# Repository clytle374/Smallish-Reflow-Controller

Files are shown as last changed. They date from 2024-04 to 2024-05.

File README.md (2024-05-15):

# Smallish-Reflow-Controller

This code started as Tiny Reflow Controller and adapted and modified https://github.com/rocketscream/TinyReflowController  While some of the original code still exists like much of the display, it was more of a teaching tool for me at this point.

This runs on a ATmega644PA processor on a MightyCore board for development. So the MightyCore board library needs loaded to build with the Arduino IDE. It uses a 128x64 OLED display with the SSD1306 driver and MAX6675 thermocouple chip plus outputs for SSR(I also added a 4N35 opto), servo and buzzer.

Here is the basic setup of the reflow profiles.  There are 2 profiles one for lead and another for lead free, the parameters in this chart have separate entries for each profile.

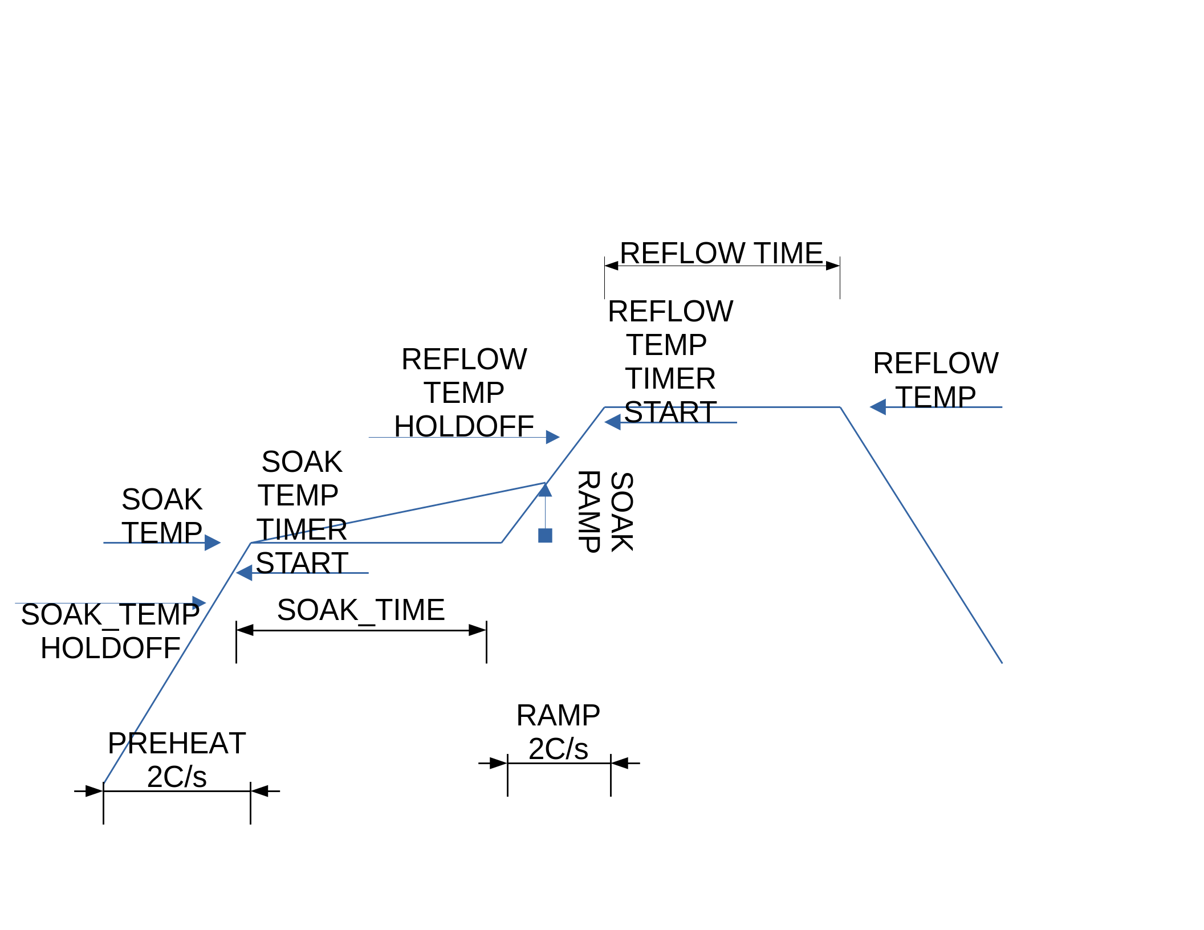
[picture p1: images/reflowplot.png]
Parameters and useage


This is a overview of the settings, more later on the oven and how the code works.  Preheat is set at 2C/s. If your oven cannot hold a 2C/s ramp, I am not sure this code will work out very well on your oven. The ramp will continue until the SOAK_TEMP_HOLDOFF is reached.  Its value is the number of degrees before the SOAK_TEMP. So if SOAK_TEMP is 150C and SOAK_TEMP_HOLDOFF is 25C then the elements will cut out at 125C. Temperature overshoot will come close to reaching the SOAK_TEMP. The SOAK_TIME will start when SOAK_TIMER_TEMP is reached. If the delta temp becomes too low during this the time the program will start adding small pulses of temperature increase, the display will show “RECOVER” at the bottom. There is an option for adding in a SOAK_RAMP to increase the temp linearly over the soak cycle, setting it to 0 disables it.

At the end of the soak cycle a 2C/s ramp is started.  Just like the SOAK_TEMP_HOLDOFF the heaters will cutoff at the value of REFLOW_TEMP_HOLDOFF before REFLOW_TEMP temp is reached. Once REFLOW_TIMER_TEMP is reached the timer will start and hold temperature until the set REFLOW_TIME is reached.

Why use those holdoff values?  I could not tune the PID of the system to not overshoot severely and hold a steady temperature. In researching this issue I found this quote “The unfortunate relationship between servo systems and oscillators is very apparent in thermal control systems.” by  Jim Williams

Results
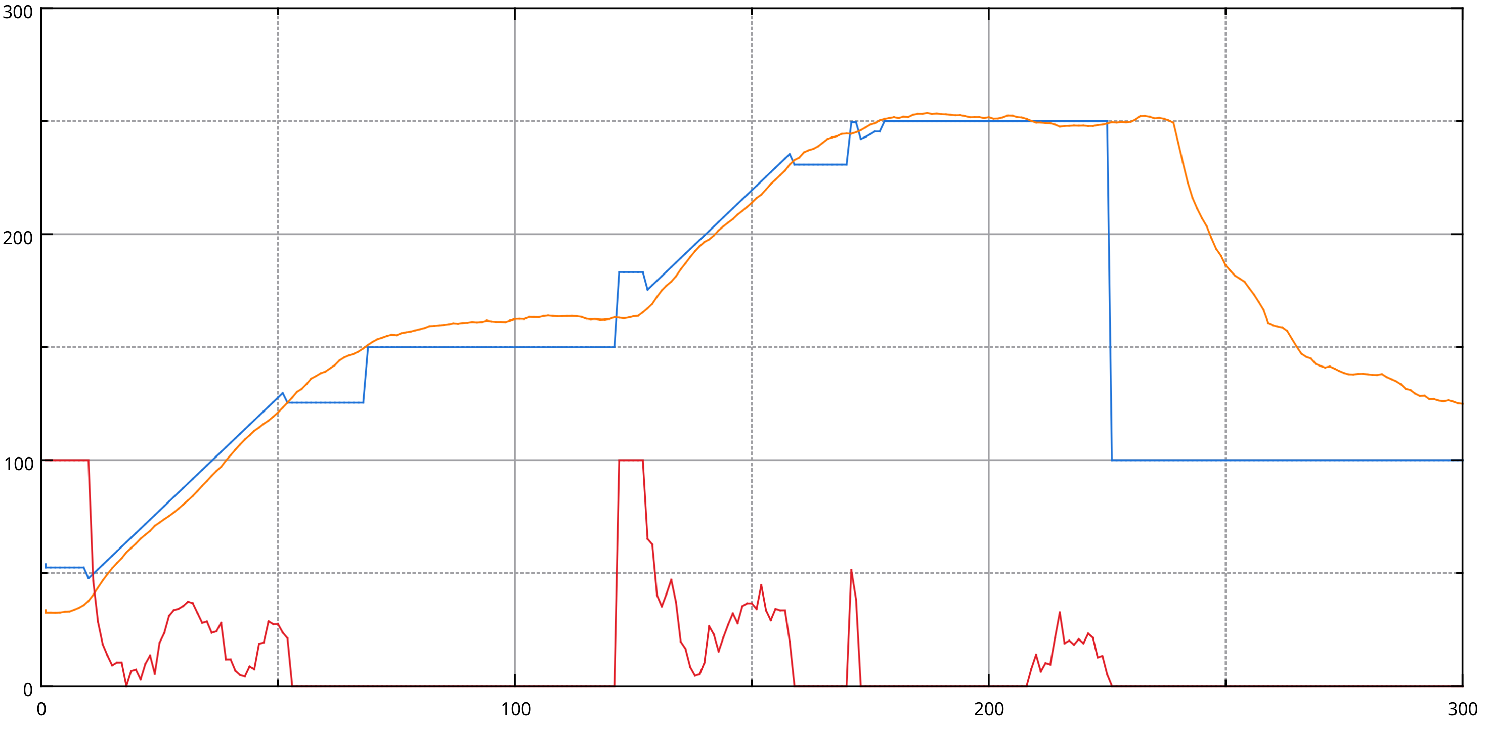
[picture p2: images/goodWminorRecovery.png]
Good Run

Blue= Setpoint       Orange= Temperature        Red= Output %
You can see the recovery right before the oven hits reflow temp. Below is an example of the TEMP_HOLDOFF values being too large making the reflow cycle too long.
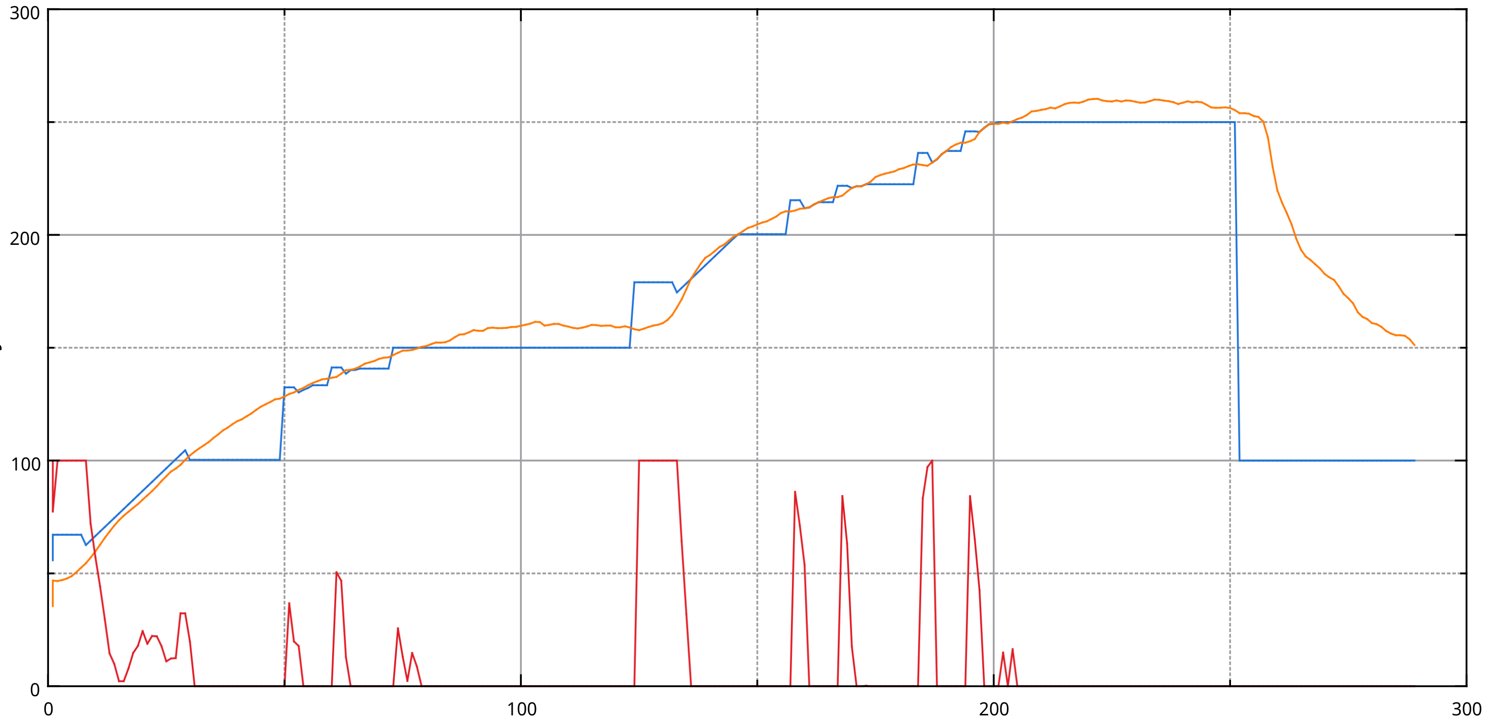
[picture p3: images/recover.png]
Too much Recovery


The oven is based on a $20 toaster oven from Walmart (MS54100112163), 2 of them actually as the whole oven is cheaper than one heating element. Each oven has a 470 watt and 580 watt quartz elements.  The oven was fitted with an insert made from the second oven and aluminum flashing as the top half of the chamber for less heat mass. It was insulated with Kaowool, and cheap aluminum coated fiberglass adhesive on the inside. The quarts tubes were cut shorter with a diamond wheel in a dreamil tool and all 4 were put in the bottom, giving about 2KW.  In hindsight I would have tried using aluminum flashing with koawool across the bottom/back/top before I cut the elements. 4 holes were drilled though the oven sides and into the chamber.  Sheet metal screws were then used as stay bolts to hold it in place.  One of the element shields was used at the bottom front to protect the glass due to their close proximity.  It might not be needed, but it greatly stiffens the chamber.

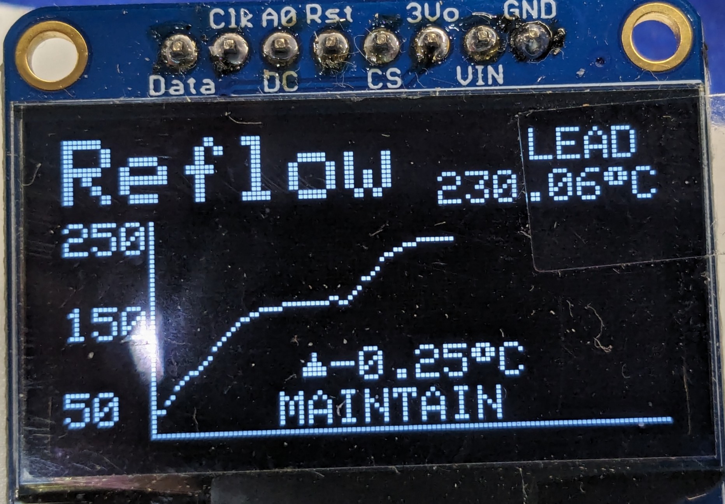
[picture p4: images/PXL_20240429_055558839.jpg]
Display

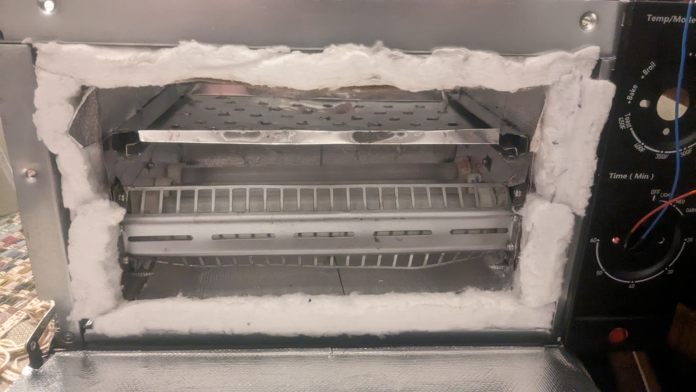
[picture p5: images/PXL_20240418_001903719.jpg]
Chamber Installed

Making the chamber
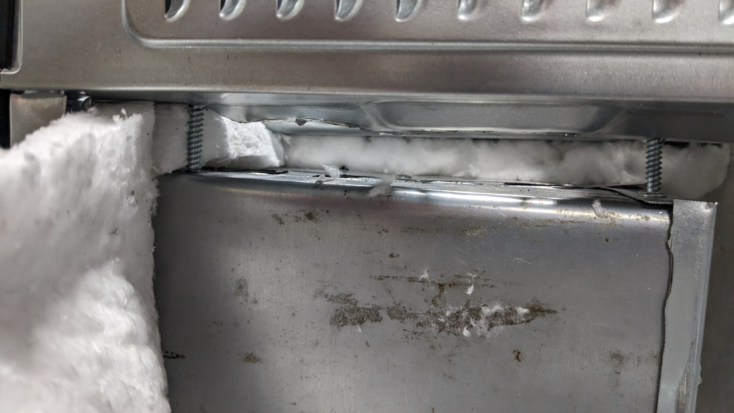
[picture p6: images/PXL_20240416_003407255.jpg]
Staybolts

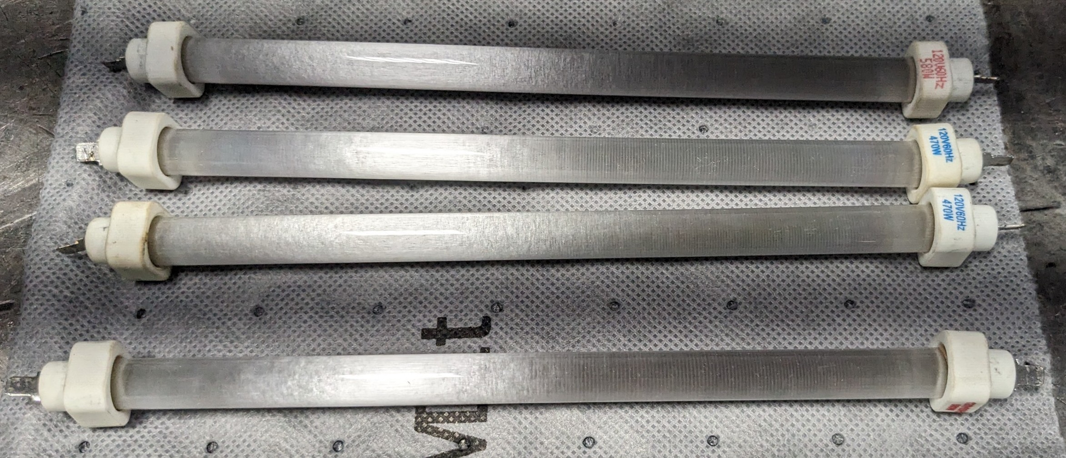
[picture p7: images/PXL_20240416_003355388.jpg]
Cut down elements

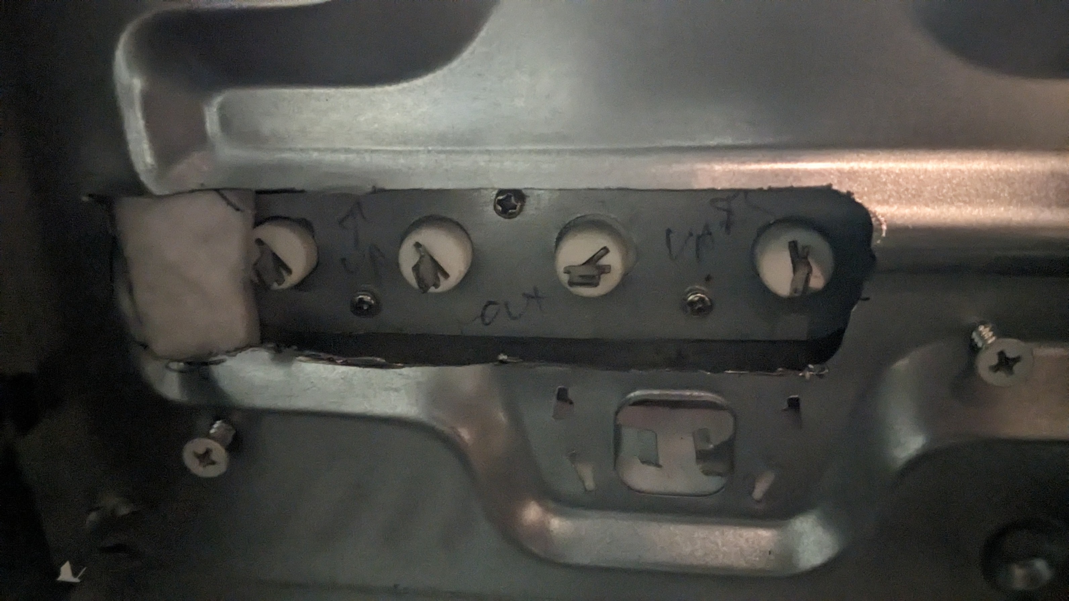
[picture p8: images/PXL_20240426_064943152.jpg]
elements holder


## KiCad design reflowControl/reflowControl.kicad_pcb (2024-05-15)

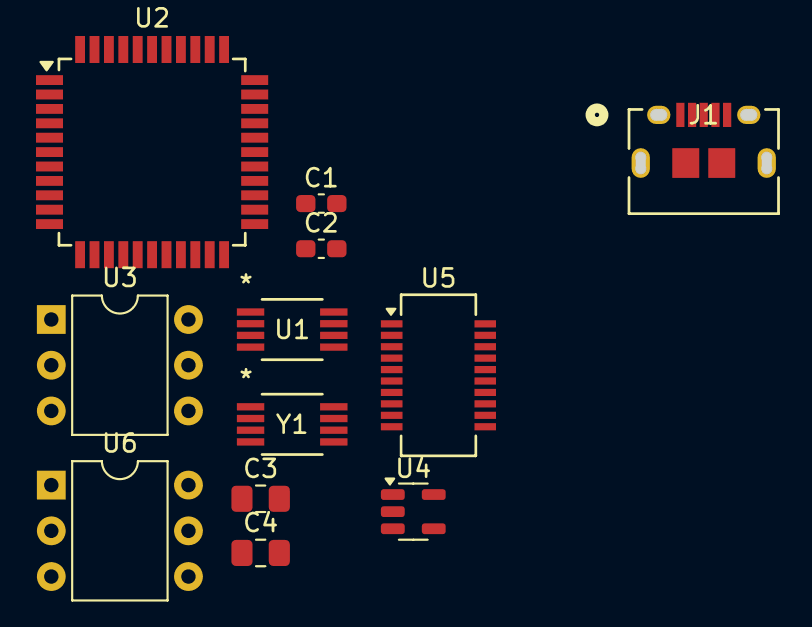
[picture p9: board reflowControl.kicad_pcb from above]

Board: 2 copper layers, 12 parts (0 on the bottom side), 6 nets, no tracks yet.

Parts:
C1, C2: 1u; C_0603_1608Metric_Pad1.08x0.95mm_HandSolder
C3, C4: 22p; C_0805_2012Metric_Pad1.18x1.45mm_HandSolder
J1: 10118194-0001LF; CONN_10118194-0001LF_AMP
U1: MAX6675ISA+; 21-0041B_8_MXM-M
U2: ATmega644PA-A; TQFP-44_10x10mm_P0.8mm
U3, U6: 4N35; DIP-6_W7.62mm
U4: MIC5317-3.3xM5; SOT-23-5
U5: FT231XS; SSOP-20_3.9x8.7mm_P0.635mm
Y1: Crystal; 21-0041B_8_MXM-M

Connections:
GND: C1.2, C2.2, C3.2, C4.2, U2.6 (GND), U2.18 (GND), U2.28 (GND), U2.39 (GND), U3.2, U4.2 (GND)
unnamed: U2.5 (VCC), U2.17 (VCC), U2.38 (VCC)
unnamed: C3.1, U2.8 (XTAL1), Y1.1
unnamed: C4.1, U2.7 (XTAL2), Y1.2
unnamed: C1.1, U4.1 (VIN), U4.3 (EN)
unnamed: C2.1, U4.5 (VOUT)

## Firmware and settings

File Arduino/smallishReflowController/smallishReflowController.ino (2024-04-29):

#define version 38

/*Title: Smallish Reflow Controller
  Date: 04-26-2024
  Author: Cory Lytle  KO4SWI

  This code was taken from Tiny Reflow Controller and adapted and modified, only 
  some parts of the structure remain, and its exellent display code.
  Thermocouple controller was changed to a MAX6657 and buttons were 
  replaced with a encoder button to enable settings configuration at the panel.
  The origonal code wouldn't run from on a 328P due to, I believe, running out of memory.  
  So it was moved to a ATmega644 processor on a MightyCore board for development. 
  So the MightyCore board needs loaded to build with the Arduino IDE.
  A servo to open the door is being added.   
  https://github.com/clytle374/Smallish-Reflow-Controller


  V31 organizing and commenting    
  V32 fixing menus, some bugs(known) remain        
  V33 fixed menus minor tweeks and the modes only moving 1 way with encoder        
  V34 clean, fix menus still, removed dead code,  
  V35 deleting extra junk, a few misc bugs
  V36 more cleanup, removed hardcoded values, work on soak ramp option
  V37 test and fix changes from above.  Need to figure out servo parameters.
  //^^ closed degrees.  Max open degrees. Open for cool ramp for both lead and ROHS?
  V38  found several issues, learned new text strings method that fixed running
  //^^ out of ram and getting trash on the display.  Fixed horriable soak slope issues
  */


//*****************************************************
//********* watchdog is running  *******
//********* charge pump the SSR supply? ***************
//*****************************************************


// ***** INCLUDES *****
#include <SPI.h>   // pulled in by SSD1306?
#include <Wire.h>  // pulled in by SSD1306SOAK_MICRO_PERIOD_PB?
#include <EEPROM.h>
#include <Adafruit_GFX.h>
#include <Adafruit_SSD1306.h>
#include <MAX6675.h>        //https://github.com/RobTillaart/MAX6675
#include <PID_v1.h>         //https://github.com/br3ttb/Arduino-PID-Library
#include <EncoderButton.h>  //https://github.com/Stutchbury/EncoderButton
#include <avr/wdt.h>        // watchdog timer
#include <Servo.h>
//#include <Watchdog.h> //Nadav Matalon   https://github.com/nadavmatalon/WatchDog

#include "smallishReflowController.h"

// ***** TYPE DEFINITIONS *****
typedef enum REFLOW_STATE {  //states for switch statments
  IDLE,
  PREHEAT,
  SOAK,
  REFLOW,
  COOL,
  COMPLETE,
  TOO_HOT,
  ERROR,
  PROGRAM
} reflowState_t;

//states for the reflow modes
typedef enum CURRENT_FUNCTION {  //functions for switch statments
  INTERCEPT,
  RAMP,
  COAST,
  SLOPE,
  MAINTAIN,
  RECOVER,
} currentFunction_t;

typedef enum REFLOW_STATUS {  //reflow yes or no, why not bool?
  OFF,
  ON
} reflowStatus_t;


typedef enum REFLOW_PROFILE {  //switch for ROHS, lead, Program mode
  REFLOW_PROFILE_LEADFREE,
  REFLOW_PROFILE_LEADED,
  PROGRAM_MODE
} reflowProfile_t;


// ***** PID CONTROL VARIABLES *****
double setpoint;    //target temp
double input = 21;  //zero will throw errors before first averaged sample
double outputMain;  //output from PID for main element

//unsorted parameters for whatnots
int windowSize;
unsigned long windowStartTime;
unsigned long nextCheck;    // time keeping variable
unsigned long nextRead;     //next read of thermouple
unsigned long updateLcd;    //display update interval
unsigned long systemTimer;  //timer for running everything in run modes
unsigned long soakTimer;    //timer for soaking
unsigned long reflowTimer;  //timer for relow
unsigned long buzzerPeriod;
unsigned long recoverTimer;
double lastTemp;  //temp last scan

//these are used to pass the diffrent ROHS or lead parameters to the system
unsigned long soakTempHoldoff;  //cut before we get to temp
unsigned long soakTemp;
unsigned long soakStartTemp;
unsigned long soakTempRamp;
unsigned long soakTime;
unsigned long reflowTempHoldoff;
unsigned long reflowTemp;
unsigned long reflowStartTemp;
unsigned long reflowTime;
unsigned long doorOpen;


reflowState_t reflowState;          // Reflow oven controller state machine state variable
reflowStatus_t reflowStatus;        // Reflow oven controller status
reflowProfile_t reflowProfile;      // Reflow profile type
currentFunction_t currentFunction;  //functions inside each state

unsigned int timerSeconds;  // Seconds timer for serial data out, or more?
unsigned int fault;         // Thermocouple fault status variable DOESN'T WORK
unsigned int timerUpdate;
unsigned char temperature[SCREEN_WIDTH - X_AXIS_START];
unsigned char x;
int encoder;                 //stored encoder couunts
bool button = 0;             // is button pressed?
int programPointer = 0;      //what is the current position of the programming menu
int lastPointer;             //save state to catch change
int menuPointer = 10;        // move selector back to parameters
bool edit = 1;               // sw back to edit mode
int menuYes = 0;             // IDK, look into this
int currentBaudPointer = 0;  // pointer for selecting baudrates from list, should be local?
double deltaTemp;
double px[41];  //parameters



// ***** LCD MESSAGES *****
const char* lcdMessagesReflowStatus[] = {  //text for display
  "Ready",
  "Pre",
  "Soak",
  "Reflow",
  "Cool",
  "Done!",
  "Hot!",
  "Error",
  "Prog"
};

// these are the texts for the menu.
const char menuOptions[][4] = { "NO", "YES" };  //display for ON/OFF menu options
const char* parameterNames[] = { "TEMPERATURE_ROOM",
                                 "LF_SOAK_TEMP_HOLDOFF",
                                 "LF_SOAK_TEMP",
                                 "LF_SOAK_TIMER_TEMP",
                                 "LF_SOAK_TIME",
                                 "LF_SOAK_RAMP_TEMP",
                                 "LF_REFLOW_TEMP_HOLFOF",
                                 "LF_REFLOW_TEMP",
                                 "LF_REFLOW_TIMER_TEMP",
                                 "LF_REFLOW TIME",
                                 "LF_DOOR_OPEN_DEG",
                                 "PB_SOAK_TEMP_HOLDOFF",
                                 "PB_SOAK_TEMP",
                                 "PB_SOAK_TIMER_TEMP",
                                 "PB_SOAK_TIME",
                                 "PB_SOAK_RAMP_TEMP",
                                 "PB_REFLOW_TEMP_HOLDOF",
                                 "PB_REFLOW_TEMP",
                                 "PB_REFLOW_TIMER_TEMP",
                                 "PB_REFLOW_TIME",
                                 "PB_DOOR_OPEN_DEG",
                                 "PID_KP_PREHEAT_MAIN ",
                                 "PID_KI_PREHEAT_MAIN",
                                 "PID_KD_PREHEAT_MAIN",
                                 "PID_KP_SOAK_MAIN",
                                 "PID_KI_SOAK_MAIN",
                                 "PID_KD_SOAK_MAIN",
                                 "PID_KP_REFLOW_MAIN",
                                 "PID_KI_REFLOW_MAIN",
                                 "PID_KD_REFLOW_MAIN",
                                 "MAX_ON   1 to 100%",
                                 "TEMPERATURE_COOL_MIN",
                                 "DOOR_CLOSED_DEG",
                                 "DOOR_FULL_OPEN_DEG",
                                 "SERIAL_SPEED",
                                 "EXIT",
                                 "DUMP_TO_SERIAL",
                                 "LOAD_DEFAULT_SETTINGS",
                                 "SAVE_TO_EEPROM" };



const char* currentFunctionText[] = {  //names for Functions
  "INTERCEPT",
  "RAMP",
  "COAST",
  "SLOPE",
  "MAINTAIN",
  "RECOVER"
};
//this will load the defaults parameters.. menu will use to load to defaults
const double defaultpx[41] = { TEMPERATURE_ROOM,
                               LF_SOAK_TEMP_HOLDOFF,
                               LF_SOAK_TEMP,
                               LF_SOAK_TIMER_TEMP,
                               LF_SOAK_TIME,
                               LF_SOAK_RAMP_TEMP,
                               LF_REFLOW_TEMP_HOLFOFF,
                               LF__REFLOW_TEMP,
                               LF_REFLOW_TIMER_TEMP,
                               LF_REFLOW_TIME,
                               LF_DOOR_OPEN_DEG,
                               PB_SOAK_TEMP_HOLDOFF,
                               PB_SOAK_TEMP,
                               PB_SOAK_TIMER_TEMP,
                               PB_SOAK_TIME,
                               PB_SOAK_RAMP_TEMP,
                               PB_REFLOW_TEMO_HOLDOFF,
                               PB_REFLOW_TEMP,
                               PB_REFLOW_TIMER_TEMP,
                               PB_REFLOW_TIME,
                               PB_DOOR_OPEN_DEG,
                               PID_KP_PREHEAT_MAIN,
                               PID_KI_PREHEAT_MAIN,
                               PID_KD_PREHEAT_MAIN,
                               PID_KP_SOAK_MAIN,
                               PID_KI_SOAK_MAIN,
                               PID_KD_SOAK_MAIN,
                               PID_KP_REFLOW_MAIN,
                               PID_KI_REFLOW_MAIN,
                               PID_KD_REFLOW_MAIN,
                               MAX_ON_MAIN,
                               TEMPERATURE_COOL_MIN,
                               DOOR_CLOSED_DEG,
                               DOOR_FULL_OPEN_DEG,
                               SERIAL_SPEED,
                               0,
                               0,
                               0,
                               0 };



//uncomment this when skipping loading the eeprom
// *******************   BROKEN    ****************
/*double px[31] = { TEMPERATURE_ROOM, LF_SOAK_TEMP_HOLDOFF, LF_SOAK_TEMP,
                  LF_SOAK_TIME, LF_SOAK_RAMP_TEMP, LF_REFLOW_TEMP_HOLFOFF, LF__REFLOW_TEMP,
                  LF_REFLOW_TIME, PB_SOAK_TEMP_HOLDOFF, PB_SOAK_TEMP, PB_SOAK_TIME,
                  PB_SOAK_RAMP_TEMP, PB_REFLOW_TEMO_HOLDOFF, PB_REFLOW_TEMP, PB_REFLOW_TIME,
                  PID_KP_PREHEAT_MAIN, PID_KI_PREHEAT_MAIN, PID_KD_PREHEAT_MAIN, PID_KP_SOAK_MAIN,
                  PID_KI_SOAK_MAIN, PID_KD_SOAK_MAIN, PID_KP_REFLOW_MAIN, PID_KI_REFLOW_MAIN,
                  PID_KD_REFLOW_MAIN, MAX_ON_MAIN, TEMPERATURE_COOL_MIN, SERIAL_SPEED };


*/

//availble baud rates, did I miss anything important?
const double baudRates[14] = { 2400, 4800, 9600, 14400, 19200, 28800, 38400, 57600,
                               74800, 115200, 230400, 250000, 500000, 1000000 };


// PID control initalize // PID values are garbage now since I can not load eeprom yet
PID reflowOvenPIDmain(&input, &outputMain, &setpoint, 100, .025, 20, DIRECT);

//initalize oled display
Adafruit_SSD1306 oled(SCREEN_WIDTH, SCREEN_HEIGHT, &Wire, -1);

// MAX6675 thermocouple interface
MAX6675 thermoCouple(MAX6675_CS_PIN, &SPI);  //sets up the thermocouple chip

EncoderButton eb1(ROTARY_PIN1, ROTARY_PIN2, BUTTON_PIN);  //sets up the encoder buton

Servo doorServo;  // create servo object to control a servo

void setup() {
  for (int i = 0; i < EXIT; i++) {  //this loop loads eeprom into parameters

    //EEPROM.put(EEPROM_STORAGE_ADDRESS + (i*4) , px[i]);   //this loads eeprom from parameters
    EEPROM.get(EEPROM_STORAGE_ADDRESS + (i * 4), px[i]);  //this loads parameters from eeprom
  }
  for (int i = EXIT; i < SAVE_TO_EEPROM; i++) {  //clear the commands parameters
    px[i] = 0;
  }


  //Serial.begin(SERIAL_SPEED); //trash
  Serial.begin(px[SERIAL_BAUD]);  //set serial speed
  // Check current selected reflow profile
  unsigned char value;  // = EEPROM.read(PROFILE_TYPE_ADDRESS);
  EEPROM.get(PROFILE_TYPE_ADDRESS, value);
  if ((value == 0) || (value == 1)) {
    // Valid reflow profile value
    reflowProfile = value;
  } else {
    // Default to lead-free profile
    EEPROM.put(PROFILE_TYPE_ADDRESS, 0);
    reflowProfile = REFLOW_PROFILE_LEADFREE;
  }

  // SSR pin initialization to ensure reflow oven is off
  digitalWrite(SSR_MAIN, LOW);
  pinMode(SSR_MAIN, OUTPUT);

  // Buzzer pin initialization to ensure annoying buzzer is off
  digitalWrite(BUZZER_PIN, LOW);
  pinMode(BUZZER_PIN, OUTPUT);

  // LED pins initialization and turn on upon start-up (active high)
  pinMode(LED_PIN, OUTPUT);
  digitalWrite(LED_PIN, HIGH);

  //Rocoder switch events
  eb1.setClickHandler(onEb1Clicked);
  eb1.setEncoderHandler(onEb1Encoder);

  SPI.begin();
  // Initialize thermocouple interface
  thermoCouple.begin();
  thermoCouple.setSPIspeed(2500000);
  //thermocouple.setThermocoupleType(MAX6675);

  // Start-up splash
  digitalWrite(BUZZER_PIN, HIGH);  //buzz on

  if (!oled.begin(SSD1306_SWITCHCAPVCC, 0x3D)) {     //setup oled set to internal power and it's address
    Serial.println(F("SSD1306 allocation failed"));  //if that didn't work then
    for (;;)
      ;  // Don't proceed, loop forever
  }


  oled.display();  //start display

  digitalWrite(BUZZER_PIN, LOW);  //buzz off
  delay(1000);

  oled.clearDisplay();  //bunch of display stuff
  oled.setTextSize(1);
  oled.setTextColor(WHITE);
  oled.setCursor(0, 0);
  oled.println(F("   Smallish Reflow"));
  oled.println(F("     Controller"));
  oled.println();
  oled.print(F("       V."));
  oled.print(version);
  oled.println();
  oled.println(F("      04-21-24"));
  oled.display();
  delay(1000);
  oled.clearDisplay();

  digitalWrite(LED_PIN, LOW);  // Turn off LED

  windowSize = 1000;  // Set window size

  nextCheck = millis();  // Initialize time keeping variable

  nextRead = millis();  // Initialize thermocouple reading variable

  updateLcd = millis();        // Initialize LCD update timer
  wdt_enable(WDTO_2S);         // Enable WDT with 1 second timeout
  doorServo.attach(SERVOPIN);  //attach door servo
  doorServo.write(0);          //zero out door servo
}

void loop() {

  unsigned long now;  // Current time
  eb1.update();       //button update
  //thermocouple read *****************************************  START
  if (millis() > nextRead) {           // Time to read thermocouple?
    wdt_reset();                       //pet the dog
    nextRead += SENSOR_SAMPLING_TIME;  // nextRead  = nextRead + SENSOR_SAMPLING_TIME
    // Read current temperature
    static int samples = 0;
    static double inputRaw[4];
    int fault = thermoCouple.read();  //figure this function out!************************
    //input = thermoCouple.getTemperature();/*
    inputRaw[samples] = thermoCouple.getTemperature();  // get the temp from the thermocouple
    samples++;
    if (samples >= 4) {
      input = (inputRaw[0] + inputRaw[1] + inputRaw[2] + inputRaw[3]) / 4;
      samples = 0;
      deltaTemp = input - lastTemp;
      lastTemp = input;
    }

    // If any thermocouple fault is detected
    if ((fault || (input < 10)))  // i think thermoCouple.read() returns a non zero value if there is a fault, TEST THIS!!!!!
    {                             // also check to see if tempature returned was  < 10C
      // Illegal operation
      reflowState = ERROR;  //error state
      reflowStatus = OFF;   //heat off
      Serial.println(F("Error"));
    }
  }
  //thermocouple read *****************************************  END

  //output data to PC, turn led on/off, and increment timerSeconds START
  if (millis() > nextCheck) {
    // Check input in the next seconds
    nextCheck += SENSOR_SAMPLING_TIME * 4;
    // If reflow process is on going
    if (reflowStatus == ON)  //is cycle running?
    {

      digitalWrite(LED_PIN, !(digitalRead(LED_PIN)));  // Toggle LED as system heart beat

      timerSeconds++;  // Increase seconds timer for reflow curve plot
      // Send temperature and time stamp to serial
      //Serial.print(F("Time"));
      Serial.print(timerSeconds);
      Serial.print(F(" "));
      Serial.print(setpoint);
      Serial.print(F(" "));
      Serial.print(input);
      Serial.print(F(" "));
      Serial.println(outputMain / 10); /*
      Serial.print(F(" "));
      Serial.println(outputBoost);*/
    } else {
      // Turn off red LED
      digitalWrite(LED_PIN, LOW);
    }
  }
  //output data to PC, turn led on/off, and increment timerSeconds ******************* END

  // update the the OLED display ***************************** START
  if (millis() > updateLcd) {
    // Update LCD in the next 100 ms
    updateLcd += UPDATE_RATE;

    oled.clearDisplay();
    oled.setTextSize(2);
    oled.setCursor(0, 0);
    oled.print(lcdMessagesReflowStatus[reflowState]);
    oled.setTextSize(1);
    if (reflowStatus == ON) {
      oled.setCursor(45, 55);
      oled.print(currentFunctionText[currentFunction]);
    }
    oled.setCursor(100, 0);  //oled.setCursor(115, 0);  shifted over to get room for prog

    if (reflowProfile == REFLOW_PROFILE_LEADFREE) {
      oled.print(F("ROHS"));
    } else if (reflowProfile == REFLOW_PROFILE_LEADED) {
      oled.print(F("LEAD"));
    } else if (reflowProfile == PROGRAM_MODE) {
      oled.print(F("PROG"));
    }
    if (reflowState != PROGRAM) {  //if we are not in program mode run preexisting program *************************
                                   // Temperature markers
      oled.setCursor(0, 18);
      oled.print(F("250"));
      oled.setCursor(0, 36);
      oled.print(F("150"));
      oled.setCursor(0, 54);
      oled.print(F("50"));
      // Draw temperature and time axis
      oled.drawLine(18, 18, 18, 63, WHITE);
      oled.drawLine(18, 63, 127, 63, WHITE);
      oled.setCursor(115, 0);

      // If currently in error state
      if (reflowState == ERROR) {
        oled.setCursor(80, 9);
        oled.print(F("TC Error"));
      } else {
        // Right align temperature reading
        if (input < 10) oled.setCursor(91, 9);
        else if (input < 100) oled.setCursor(85, 9);
        else oled.setCursor(80, 9);
        // Display current temperature
        oled.print(input);
        oled.print((char)247);
        oled.print(F("C"));
        oled.setCursor(50, 46);
        oled.print((char)0x1e);
        //oled.print(F(" "));
        if (deltaTemp >= 0) oled.print(F(" "));
        //if (deltaTemp <= 10 && deltaTemp >= -10 ) oled.print(F(" "));
        oled.print(deltaTemp);
        oled.print((char)247);
        oled.print(F("C"));
      }


      if (reflowStatus == ON) {
        // We are updating the display faster than sensor reading
        if (timerSeconds > timerUpdate) {
          // Store temperature reading every 3 s
          if ((timerSeconds % 3) == 0) {
            timerUpdate = timerSeconds;
            unsigned char averageReading = map(input, 0, 250, 63, 19);
            if (x < (SCREEN_WIDTH - X_AXIS_START)) {
              temperature[x++] = averageReading;
            }
          }
        }
      }

      unsigned char timeAxis;
      for (timeAxis = 0; timeAxis < x; timeAxis++) {
        oled.drawPixel(timeAxis + X_AXIS_START, temperature[timeAxis], WHITE);
      }
    } else {  //***************if not in a normal mode we are in
      //program by default so we will used the lower part of the screen from program mode.
      double X = px[programPointer];  //the following is to
      int shiftPlaces = 8;            //align the decimal point of all parameters in display
      if (X < 1) {
        shiftPlaces = 7;
      } else {
        for (; X >= 1; shiftPlaces--) {
          X = X * .1;
        }
      }
      oled.setTextSize(1);
      oled.setCursor(0, 18);
      oled.print(parameterNames[programPointer]);  //really bad name? lol
      oled.setCursor(30, 42);
      if (programPointer < EXIT) {
        while (shiftPlaces-- > 0)           //loop the number of time
          oled.print(F(" "));               //spaces for deciaml alignemnt
        oled.print(px[programPointer], 4);  //menuPointer programPointer edit
      } else {
        oled.print(F("   "));
        oled.print(menuOptions[menuYes]);
      }

      oled.setCursor(0, 30);
      if (edit && (menuPointer == 10)) {  //handle the pointer for parameter selection
        oled.print(F("^ ^ ^ ^ ^ ^ ^ ^ ^ ^ ^"));
      } else if (!edit && (menuPointer == 10)) {
        oled.print(F("* * * * * * * * * * "));  //now in move the pointer mode
      } else {
        oled.print(F(" "));
      }
      if (menuPointer != 10) {   //are we editing parameter values?
        oled.setCursor(30, 51);  //move cursor below target data value
        for (int i = 10; i > -1; i--) {
          if (i == 2) {
            oled.print(F(" "));
          }
          if ((i - menuPointer) == 0) {
            if (edit) {
              oled.print(F("^"));  //plave edit cursor ^ under proper digit.
            } else if (!edit) {    //place select cursor * under proper digit
              oled.print(F("*"));
            }
          } else {
            oled.print(F(" "));
          }
        }
      }

      oled.setCursor(0, 54);  //show what parameter # is being edited
      oled.print(F("P#"));
      oled.print(programPointer);  //mostly for programming debug, but nice.
    }

    // Update screen
    oled.display();
  }
  // update the the OLED display ***************************** STOP
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

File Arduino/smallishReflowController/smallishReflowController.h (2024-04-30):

// ***** CONSTANTS *****
// ***** GENERAL *****

//********** screen data *********
#define SCREEN_WIDTH 128  // OLED display width, in pixels
#define SCREEN_HEIGHT 64  // OLED display height, in pixels
#define X_AXIS_START 18   // X-axis starting position
#define UPDATE_RATE 100   //display

// ***** GENERAL PROFILE CONSTANTS *****
#define PROFILE_TYPE_ADDRESS 0    //eeprom address for current profile
#define EEPROM_STORAGE_ADDRESS 1  //eeprom address for everything else
#define SENSOR_SAMPLING_TIME 250  // time for thermocouple reads, DON'T CHANGE
#define PID_SAMPLE_TIME 1000      //pid loop time

//********** begin paramters saved in eeprom *****************
#define TEMPERATURE_ROOM 50  //parameter 0
#define ROOM_TEMP 0


// ***** LEAD FREE PROFILE CONSTANTS *****
#define LF_SOAK_TEMP_HOLDOFF 25  //cut heaters before reaching reflow temp
#define ROHS_SOAK_TEMP_HOLDOFF 1
#define LF_SOAK_TEMP 150            //soak set temp
#define ROHS_SOAK_TEMP 2            //^^ parameter number
#define LF_SOAK_TIMER_TEMP 140      //start the timer here
#define ROHS_SOAK_TIMER_TEMP 3      //^^ parameter number
#define LF_SOAK_TIME 60000          //set soak time
#define ROHS_SOAK_TIME 4            //^^ parameter number
#define LF_SOAK_RAMP_TEMP 0         //do we want to ramp tem pduring soak?
#define ROHS_SOAK_TEMP_RAMP 5       //^^ parameter number
#define LF_REFLOW_TEMP_HOLFOFF 20   //cut heater off before reflow temp
#define ROHS_REFLOW_TEMP_HOLDOFF 6  //^^ parameter number
#define LF__REFLOW_TEMP 250         //reflow temp
#define ROHS_REFLOW_TEMP 7          //^^ parameter number
#define LF_REFLOW_TIMER_TEMP 230    //start the timer here
#define ROHS_REFLOW_TIMER_TEMP 8    //^^ parameter number
#define LF_REFLOW_TIME 30000        //reflow time
#define ROHS_REFLOW_TIME 9          //^^ parameter number
#define LF_DOOR_OPEN_DEG 90         //how far to open the door
#define ROHS_DOOR_OPEN_DEG 10       //

// ***** LEADED PROFILE CONSTANTS *****
#define PB_SOAK_TEMP_HOLDOFF 25      //cut heater before reaching soak
#define LEAD_SOAK_TEMP_HOLDOFF 11    //^^ parameter number
#define PB_SOAK_TEMP 150             //temp to soak
#define LEAD_SOAK_TEMP 12            //^^ parameter number
#define PB_SOAK_TIMER_TEMP 140       //start the timer here
#define LEAD_SOAK_TIMER_TEMP 13      //^^ parameter number
#define PB_SOAK_TIME 60000           //time to soak
#define LEAD_SOAK_TIME 14            //^^ parameter number
#define PB_SOAK_RAMP_TEMP 0          //do we want to ramp tem pduring soak?
#define LEAD_SOAK_TEMP_RAMP 15       //^^ parameter number
#define PB_REFLOW_TEMO_HOLDOFF 25    //cut heater before reflow
#define LEAD_REFLOW_TEMP_HOLDOFF 16  //^^ parameter number
#define PB_REFLOW_TEMP 224           //reflow temp
#define LEAD_REFLOW_TEMP 17          //^^ parameter number
#define PB_REFLOW_TIMER_TEMP 204     //start the timer here
#define LEAD_REFLOW_TIMER_TEMP 18    //^^ parameter number
#define PB_REFLOW_TIME 30000         //reflow time
#define LEAD_REFLOW_TIME 19          //^^ parameter number
#define PB_DOOR_OPEN_DEG 90          //how far to open the door
#define LEAD_DOOR_OPEN_DEG 20        //^^ parameter number


// ***** PID PARAMETERS *****
// ***** PRE-HEAT *****
#define PID_KP_PREHEAT_MAIN 100    //parameter10
#define PID_P_PREHEAT 21           //^^ parameter number
#define PID_KI_PREHEAT_MAIN 0.015  //parameter11
#define PID_I_PREHEAT 22           //^^ parameter number
#define PID_KD_PREHEAT_MAIN 100    //parameter12
#define PID_D_PREHEAT 23           //^^ parameter number

// ***** SOAK *****
#define PID_KP_SOAK_MAIN 100    //parameter16
#define PID_P_SOAK 24           //^^ parameter number
#define PID_KI_SOAK_MAIN 0.015  // parameter17
#define PID_I_SOAK 25           //^^ parameter number
#define PID_KD_SOAK_MAIN 100    //parameter18
#define PID_D_SOAK 26           //^^ parameter number

// ***** REFLOW STAGE *****
#define PID_KP_REFLOW_MAIN 100    // parameter22
#define PID_P_REFLOW 27           //^^ parameter number
#define PID_KI_REFLOW_MAIN 0.015  //parameter23
#define PID_I_REFLOW 28           //^^ parameter number
#define PID_KD_REFLOW_MAIN 100    //parameter24
#define PID_D_REFLOW 29           //^^ parameter number

//others
#define MAX_ON_MAIN 100           // % limit max ontime of element 0-100 // parameter28
#define MAX_HEATER_ON 30          //^^ parameter number
#define TEMPERATURE_COOL_MIN 100  //min temp to complete cool
#define COOL_TEMP 31              //^^ parameter number
#define DOOR_CLOSED_DEG 0         // what servo angle closes door
#define DOOR_CLOSE 32             //^^ parameter number
#define DOOR_FULL_OPEN_DEG 180    //max door opening.
#define DOOR_MAX 33               //^^ parameter number

// ****** serial speed ********
#define SERIAL_SPEED 115200  //serial com speed parameter 36
#define SERIAL_BAUD 34       //^^ parameter number
//********** end paramters saved in eeprom *****************
#define EXIT 35
#define DUMP_TO_SERIAL 36
#define LOAD_DEFAULTS 37
#define SAVE_TO_EEPROM 38


//Pin assignments
#define ROTARY_PIN1 10    //D16 PC0 PCINIT16 SCA encoder
#define ROTARY_PIN2 11    //D17 PC1 PCINIT17 SCL encoder
#define BUTTON_PIN A1     //D25 PA1 PCINIT1 ADC1 encoder button
#define SSR_MAIN 12       //SSR PIN
#define LED_PIN 0         //led pin
#define BUZZER_PIN 13     //buzzer pin
#define SERVOPIN A0       //servo PWM
#define MAX6675_CS_PIN 1  //chip select max6675 thermocouple

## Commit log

2024-04-23 arduino code added
2024-04-23 fixed git in subfolder
    [smallishReflowController.ino]
2024-04-23 V32 fixing menus, still some bugs
    [smallishReflowController.ino]
2024-04-23 V33 fixed menus, tweeks, mode select knob improved
    [smallishReflowController.ino]
2024-04-23 V34 fixing menus still, eeprom fixed, code cleanup
    [smallishReflowController.ino]
2024-04-23 V35 cleanup, random bugs, bedtime
    [smallishReflowController.ino]
2024-04-25 starting PCB
    [reflowControl.kicad_pcb, reflowControl.kicad_sch]
2024-04-26 added delta C,fixed overshoot issue in coast function, PCB parts,
    [reflowControl.kicad_sch]
2024-04-26 V38 improved code as memory was low, soak caost is fixed
    [reflowControl.kicad_sch]
2024-04-28 fixed bug with delta T, played with formatting display
    [smallishReflowController.h, smallishReflowController.ino]
2024-04-29 fixed where the timer start setpoints could be lower than setpoint, display picture
    [smallishReflowController.h, smallishReflowController.ino]
2024-04-30 schematic work
    [reflowControl.kicad_sch]

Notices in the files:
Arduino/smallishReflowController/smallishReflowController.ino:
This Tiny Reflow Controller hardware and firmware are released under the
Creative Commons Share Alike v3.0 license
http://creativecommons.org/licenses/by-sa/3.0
